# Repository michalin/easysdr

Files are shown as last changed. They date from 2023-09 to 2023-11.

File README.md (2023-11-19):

# SDR Receiver Using a Tayloe Quadrature Detector
 Simple SDR Receiver that can receive frequencies up to approximately 30MHz, if an optional Si5351 clock generator is used. Without this, it receives up to about 20MHz, using the ESP32 clock dividers. The circuit is so simple that it can even be built on a breadboard.   

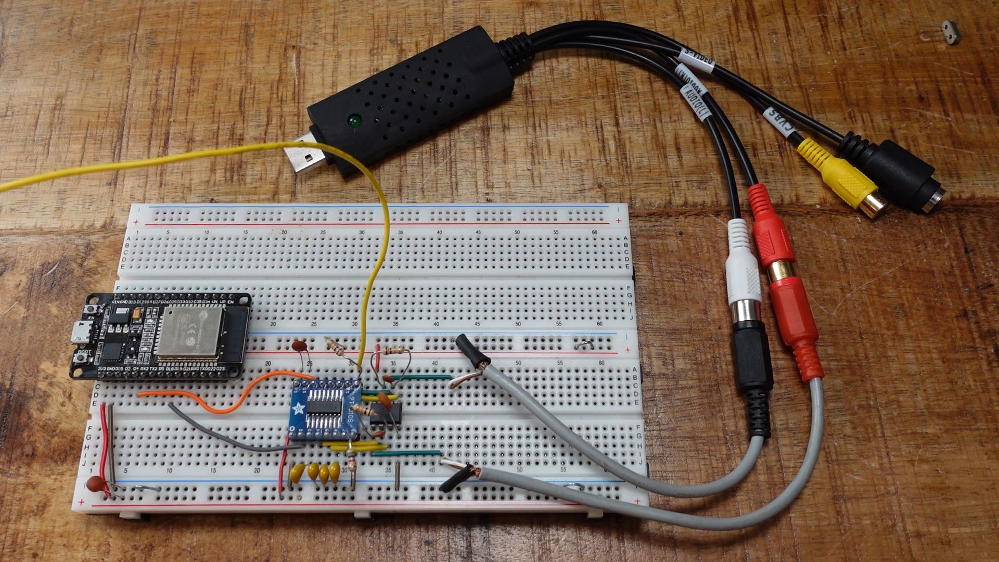
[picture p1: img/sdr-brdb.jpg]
 Tayloe Quadrature Detector circuit on a solderless breadboard    

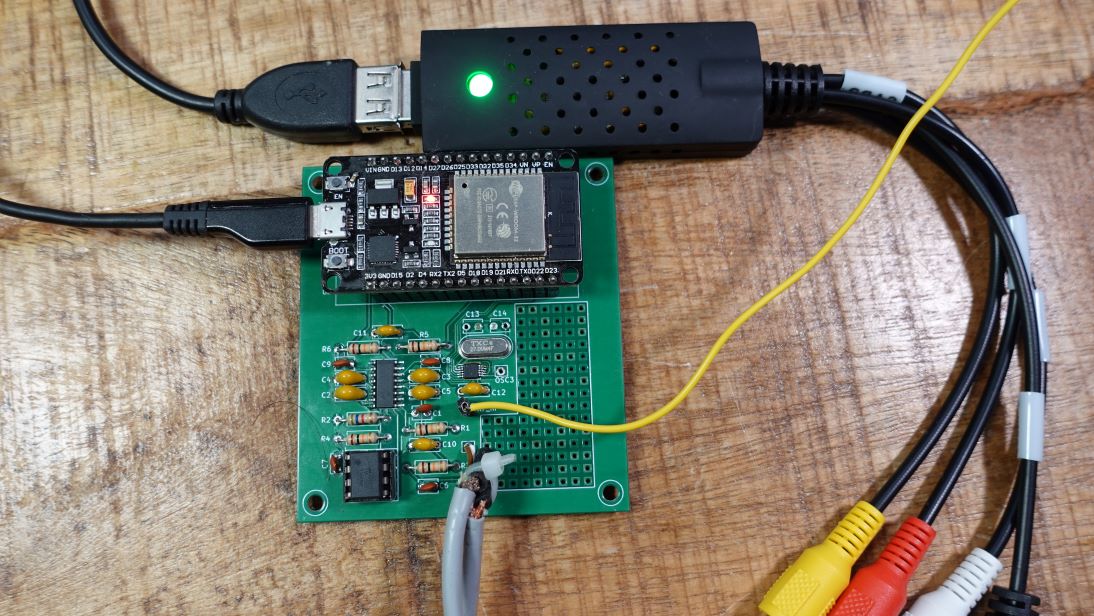
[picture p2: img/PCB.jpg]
 Circuit on a PCB with USB capture device connected

## What you need
- ESP32 Development Module
- The [circuit](schematic/schematic.pdf) on Breadboard or PCB
- Sound card or USB sound capture device with stereo input and a sample rate of at least 48 kbit/s.
- At least 10m or wire as an antenna
- Windows or Linux PC. A Raspberry Pi or similar board might also work, but I didn't test this.

## Arduino Libraries
- Etherkit Si5351 Arduino Library (if Si5351 is used)

## Installation
- Set `#define USE_SI5351 1` in the [ESP32 sketch](sketch/sketch.ino) if you are using an Si5351. 
- Flash it to your ESP32 dev module.
- Connect output "I" to the right channel and "Q" to the left channel of your sound card.

### Usage with Quisk (Windows and Linux)
- Download and install [Quisk](https://james.ahlstrom.name/quisk/)
- Make sure that TKinter is installed. If not type `sudo apt install python3-tk` or `pip install tkinter`
- Configure the serial port the ESP32 is connected to in the variable *openradio_serial_port* in [.quisk_conf.py](sketch/.quisk_conf.py), i.e. `openradio_serial_port = "/dev/ttyUSB0"` on Linux or `openradio_serial_port = "COM1"` on Windows.
- On Windows: copy the script [quisk_conf.py](quisk/quisk_conf.py) into the "Documents" folder of your user directory.
- On Linux: Copy the file into the root of your home directory and rename it to `.quisk_conf.py`
- Start [Quisk](https://james.ahlstrom.name/quisk/) and have fun.

### Usage with HDSDR (Windows only)
- Download and install [HDSDR](https://www.hdsdr.de/)
- Download and install [Omni-rig V2.1](https://www.hb9ryz.ch/omnirig)
- Copy the file [MYSDR.ini](omni-rig/MYSDR.ini) to `%APPDATA%\Afreet\Rigs`
- Start Omni-rig and set a custom rig name (i.e. RIG1), Rig-Type: 'MYRIG', your COM-Port and 115200 as baud rate
- Configure Omni-rig and HDSDR like shown in the picture below:
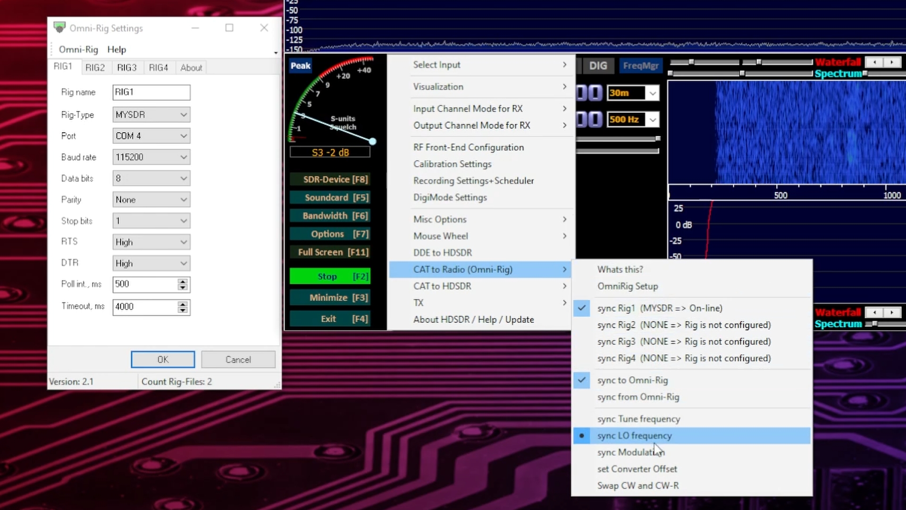
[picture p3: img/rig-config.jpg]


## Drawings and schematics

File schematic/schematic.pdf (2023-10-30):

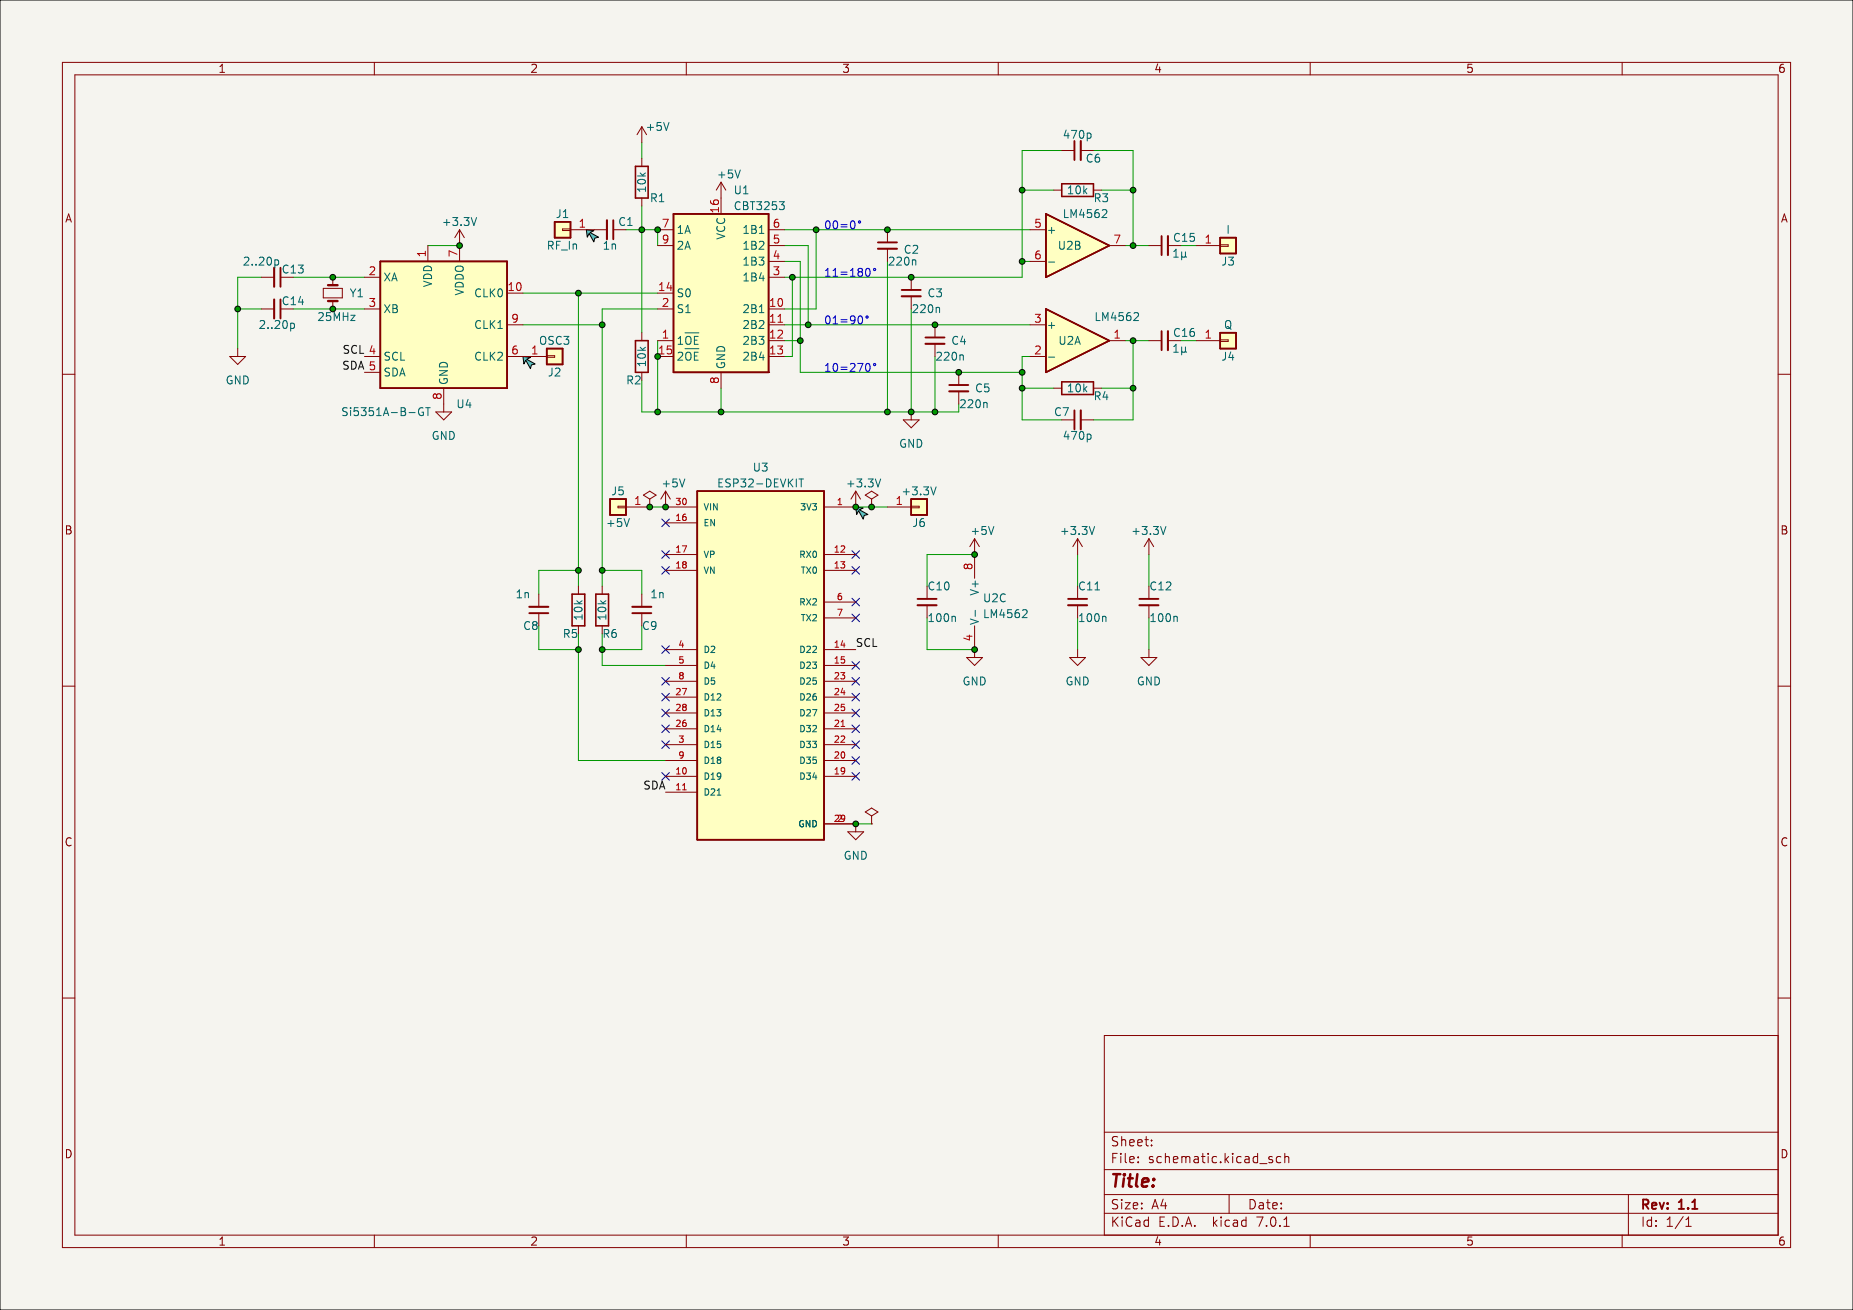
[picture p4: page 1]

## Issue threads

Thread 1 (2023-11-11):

Thanks & Omni-rig version

vgegok, 2023-11-11:
I am trying to build your magical project, and the PCB and components are already on the way. I suggest that you modify the download address of Omni-rig in README.md to the latest version (screenshot of your HDSDR settings). HDSDR V2.80+ supports Omni-rig V2.1 or newer versions:
[https://www.hb9ryz.ch/omnirig/](https://www.hb9ryz.ch/omnirig/)
Once again, this is really a great project, and I believe I can learn a lot through your project.

There seems to be a problem with my sound card. When I am not connected to the easysdr board:
There will be a very high peak in LO!
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

michalin, 2023-11-19:
Link in Readme changed.

Closed 2023-11-19.

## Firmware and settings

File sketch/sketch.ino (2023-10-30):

#include <Arduino.h>
#include <driver/ledc.h>
//#define TESTSIG 1
#define USE_SI5351 1

#define VERSION "EasySDR Firmware V1.0"

// Default output frequency
#define FREQ_LIMIT_LOWER 	48000 //Baud rate of capturing device
#if USE_SI5351
#define MAX_ESP_FREQ 		5000000
#define FREQ_LIMIT_UPPER 	30000000
#else
#define MAX_ESP_FREQ 20000000
#define FREQ_LIMIT_UPPER MAX_ESP_FREQ
#endif

#define I_CHANNEL ledc_channel_t::LEDC_CHANNEL_0
#define Q_CHANNEL ledc_channel_t::LEDC_CHANNEL_1
#define T_CHANNEL ledc_channel_t::LEDC_CHANNEL_2
#define OUTPIN_I 4
#define OUTPIN_Q 18
#define OUTPIN_T 26
#define PWMRES 2
#define PWMRES_T 1
#define DUTY_T 1
#define OFFSET_T 100000 
#define DUTY (1UL << (PWMRES - 1)) // Duty cycle 50%

#define SERIAL_BAUD 115200

#if USE_SI5351
#include <Wire.h>
#include <si5351.h>
Si5351 si5351;
#endif

uint32_t rx_frequency;

void setup();
void loop();
void set_rx_freq(uint32_t freq);

void setup()
{
	Serial.begin(SERIAL_BAUD);
	Serial.setTimeout(10);

#if USE_SI5351
	if (si5351.init(SI5351_CRYSTAL_LOAD_8PF, 27000000, 0))
		printf("Si5351 found\n");
	else
		printf("Error: Si5351 not found\n");

	//  Set output frequencies
	si5351.output_enable(SI5351_CLK2, 1);

	// Read the status register and return the chip revision ID.
	si5351.update_status();
#endif
	ledcSetup(I_CHANNEL, FREQ_LIMIT_LOWER, PWMRES);
	ledcWrite(Q_CHANNEL, DUTY);
	ledcWrite(I_CHANNEL, DUTY);
#if TESTSIG
	// Test signal generator on pin 26
	ledcSetup(T_CHANNEL, FREQ_LIMIT_LOWER + OFFSET_T, PWMRES_T);
	ledcAttachPin(OUTPIN_T, T_CHANNEL);
	ledcWrite(T_CHANNEL, DUTY_T);
#endif
}

void serialEvent()
{
	String command = Serial.readString();
	// printf("Received command: %s\n", command.c_str());
	if (command.startsWith("FREQ"))
	{
		String arg = command.substring(command.indexOf(',') + 1);
		int frq = arg.toInt();
		if (frq > FREQ_LIMIT_UPPER)
			frq = FREQ_LIMIT_UPPER;
		if (frq < FREQ_LIMIT_LOWER)
			frq = FREQ_LIMIT_LOWER;

		printf("FREQ,%d\n", frq);
		set_rx_freq(frq);
	}
	else if (command.startsWith("VER"))
	{
		printf("VER,%s\n",VERSION);
	}
}

void set_rx_freq(uint32_t freq)
{
#if USE_SI5351 // Si 5351 High-Z
	if (freq <= MAX_ESP_FREQ)
	{
		si5351.set_clock_disable(SI5351_CLK0, SI5351_CLK_DISABLE_HI_Z);
		si5351.set_clock_disable(SI5351_CLK1, SI5351_CLK_DISABLE_HI_Z);
		si5351.output_enable(SI5351_CLK0, 0);
		si5351.output_enable(SI5351_CLK1, 0);
	}
#else
	if (freq > MAX_ESP_FREQ)
		freq = MAX_ESP_FREQ;
#endif
	if (freq <= MAX_ESP_FREQ)
	{
		ledcAttachPin(OUTPIN_I, Q_CHANNEL);
		ledcAttachPin(OUTPIN_Q, I_CHANNEL);
		// Phase shift 90° (Duty cycle/2) to Channel 1
		ledc_set_duty_with_hpoint(LEDC_HIGH_SPEED_MODE, ledc_channel_t::LEDC_CHANNEL_1, DUTY, DUTY / 2);
		ledcChangeFrequency(I_CHANNEL, freq, DUTY);
		rx_frequency = freq; // (Hz)
		return;
	}

	rx_frequency = freq; // (Hz)
#if USE_SI5351
	pinMode(OUTPIN_I, INPUT);
	pinMode(OUTPIN_Q, INPUT);
	si5351.output_enable(SI5351_CLK0, 1);
	si5351.output_enable(SI5351_CLK1, 1);
	// This is for models that use the Si5351 to produce the I/Q on CLK0 and CLK1.
	uint32_t pll_freq;
	uint8_t mult;
	// mult must be less than 128 (7 bits) according to documentation
	// Determine mult so that pll frequency is >600 Mhz
	while ((pll_freq < 600000000) && (mult < 128))
	{
		pll_freq = freq * ++mult;
	}
	/*printf("nmult: %d\n", mult);
	printf("pll_freq: %d\n", pll_freq);*/

	// si5351.set_freq_manual(110000000 * 100ULL, pll_freq * 100ULL, SI5351_CLK2);
	si5351.set_freq_manual(freq * 100ULL, pll_freq * 100ULL, SI5351_CLK1);
	si5351.set_freq_manual(freq * 100ULL, pll_freq * 100ULL, SI5351_CLK0);
	// Now we can set CLK1 to have a 90 deg phase shift by entering
	// mult in the CLK1 phase register, since the ratio of the PLL to
	// the clock frequency is mult.
	si5351.set_phase(SI5351_CLK0, 0);
	si5351.set_phase(SI5351_CLK1, mult);
	// We need to reset the PLL before they will be in phase alignment
	si5351.pll_reset(SI5351_PLLA);
#endif
}

void loop()
{
}

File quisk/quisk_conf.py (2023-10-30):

# Derived from
# OpenRadio v1.1 Quisk Configuration File
# 
# IMPORTANT: To be able to control the OpenRadio board from within Quisk,
# you will need to compile and upload the 'openradio_quisk' firmware, which
# is available from: https://github.com/darksidelemm/open_radio_miniconf_2015
#
# You will also need to install the pyserial package for python.
#

from __future__ import print_function
from __future__ import absolute_import
from __future__ import division
from tkinter import messagebox
import serial,time
from quisk_hardware_model import Hardware as BaseHardware
from os import path
import sys
#import wx

# Sound card and serial port settings depending on OS
#
sample_rate = 48000					# name_of_sound_capt hardware sample rate in Hertz
openradio_serial_rate = 115200

if sys.platform == "win32":
  name_of_sound_capt = "Primary"
  name_of_sound_play = "Primary"
  openradio_serial_port = "COM1"
else:
  name_of_sound_capt = "pulse"		# Name of soundcard capture hardware device.
  name_of_sound_play = "pulse"
  openradio_serial_port = "/dev/ttyUSB0"

channel_i = 1 					# Soundcard index of in-phase channel:  0, 1, 2, ...
channel_q = 0						# Soundcard index of quadrature channel:  0, 1, 2, ...


# OpenRadio Frequency limits.
# These are just within the limits set in the openradio_quisk firmware.
openradio_lower = sample_rate
openradio_upper = 30000000

# OpenRadio Hardware Control Class
#
class Hardware(BaseHardware):
  def open(self):
    # Called once to open the Hardware
    # Open the serial port.
    try:
      self.or_serial = serial.Serial(openradio_serial_port,openradio_serial_rate,timeout=3)
    except:
      print("Error: port not open")
      messagebox.showerror("Error", "Could not open serial port")
      return False

    print("Opened Serial Port.")
    # Wait for the Arduino Nano to restart and boot.
    time.sleep(2)
    # Poll for version. Should probably confirm the response on this.
    version = str(self.get_parameter("VER"))
    print("This should be the version printed next.")
    print(version)
    # Return an informative message for the config screen
    t = version + ". Capture from sound card %s." % self.conf.name_of_sound_capt
    return t

  def close(self):      
    # Called once to close the Hardware
    self.or_serial.close()

  def ChangeFrequency(self, tune, vfo, source='', band='', event=None):
    # Called whenever quisk requests a frequency change.
    # This sends the FREQ command to set the centre frequency of the OpenRadio,
    # and will also move the 'tune' frequency (the section within the RX passband
    # which is to be demodulated) if it falls outside the passband (+/- sample_rate/2).
    print("-->ChangeFrequency Tune: {}, vfo: {}, source: {} band: {} event: {} ".format(tune,vfo,source,band,event))
    if(tune == 0 or vfo == 0):
      return 0,0

    print("Setting VFO to %dHz." % vfo)
    if(vfo<openradio_lower):
      vfo = openradio_lower
      tune = openradio_lower
      print("Outside range! Setting to %d" % openradio_lower)

    if(vfo>openradio_upper):
      vfo = openradio_upper
      tune = openradio_upper
      print("Outside range! Setting to %d" % openradio_upper)

    if(source == "BtnUpDown"):
      tune = vfo + 10000 

      #print("sample_rate =")
    #print(sample_rate)
    # If the tune frequency is outside the RX bandwidth, set it to somewhere within that bandwidth.
    if(tune>(vfo + sample_rate/2) or tune<(vfo - sample_rate/2)):
      vfo = tune -10000  #We don't care so much about the VFO.
      print("Bringing tune frequency back into the RX bandwidth.")

    success = self.set_parameter("FREQ",str(vfo))
    if success:
      print("Frequency change succeeded!")
    else:
      print("Frequency change failed.")

    return tune, vfo
  
  # Heartbeat function called every 100ms
  def ReturnFrequency(self):
    #print("-->ReturnFrequency")
    return None, None

#
# Serial comms functions, to communicate with the OpenRadio board
#

  def get_parameter(self,string):
    string = string + "\n"
    self.or_serial.write(string.encode())
    return self.get_argument()
    #return string.encode()
        
  def set_parameter(self,string,arg):
    string = string+","+arg+"\n"
    #print("Command: "+string)
    self.or_serial.write(string.encode())
      
    if self.get_argument().decode() == arg:
      return True
    return False
    
  def get_argument(self):
    data1 = self.or_serial.readline()
    print("Response: " + data1.decode())
    # Do a couple of quick checks to see if there is useful data here
    if len(data1) == 0:
       return -1
        
    if data1.find(b',') == -1:
       return -1
    
    data1 = data1.split(b',')[1].rstrip(b'\r\n')
    #print("data1 = "+data1.decode())
    
    return data1

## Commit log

2023-10-06 Update .quisk_conf.py
    Error fixed
    [.quisk_conf.py]
2023-10-30 Version 1.1
    Supports HDSDR (Omni-rig)
    Output capacitors added
    Vcc pin of CBT3253 at 5V instead of 3.3V
    [schematic-B_Cu.gbr, schematic-B_Mask.gbr, schematic-Edge_Cuts.gbr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]
